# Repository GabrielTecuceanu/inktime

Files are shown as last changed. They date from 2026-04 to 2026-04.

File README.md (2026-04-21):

# InkTime

---

## Block Diagram

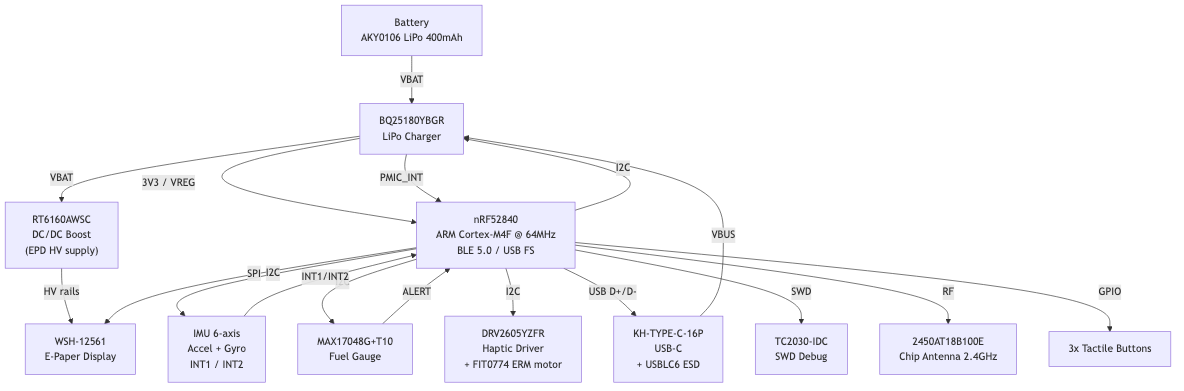
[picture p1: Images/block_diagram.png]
Block Diagram


---

## Bill of Materials (BOM)

| Ref | Component | Description | Package | JLCPCB Part | Datasheet |
| --- | --- | --- | --- | --- | --- |
| U1 | nRF52840-QIAA | MCU, BLE 5.0, ARM Cortex-M4F, 1MB Flash, 256KB RAM | AQFN-73 | [C190794](https://jlcpcb.com/partdetail/NordicSemiconductor-nRF52840_QIAA/C190794) | [Datasheet](https://infocenter.nordicsemi.com/pdf/nRF52840_PS_v1.1.pdf) |
| IC1 | BQ25180YBGR | LiPo charger, I2C, 1A, integrated power path | DSBGA-8 | [C2678722](https://jlcpcb.com/partdetail/TexasInstruments-BQ25180YBGR/C2678722) | [Datasheet](https://www.ti.com/lit/ds/symlink/bq25180.pdf) |
| U3 | MAX17048G+T10 | Fuel gauge, 1% SOC accuracy, I2C | TDFN-8 | [C82344](https://jlcpcb.com/partdetail/MaximIntegrated-MAX17048GT10/C82344) | [Datasheet](https://datasheets.maximintegrated.com/en/ds/MAX17048-MAX17049.pdf) |
| IC9 | RT6160AWSC | DC/DC boost/buck converter for EPD supply, I2C | WL-CSP-15 | Search RT6160AWSC | [Datasheet](https://www.richtek.com/assets/product_file/RT6160A/DS6160A-02.pdf) |
| IC2 | DRV2605YZFR | Haptic driver, I2C, LRA/ERM support | DSBGA-16  | [C2062186](https://jlcpcb.com/partdetail/TexasInstruments-DRV2605YZFR/C2062186) | [Datasheet](https://www.ti.com/lit/ds/symlink/drv2605.pdf) |
| IC3 | BMA423 | 3-axis accelerometer, step counter, I2C | LGA-12 | Search BMA423 | [Datasheet](https://www.bosch-sensortec.com/products/motion-sensors/accelerometers/bma423/)  |
| D3 | USBLC6-2SC6Y | USB ESD protection | SOT-23-6  | [C2827654](https://jlcpcb.com/partdetail/STMicroelectronics-USBLC62SC6Y/C2827654)  | [Datasheet](https://www.st.com/resource/en/datasheet/usblc6-2.pdf) |
| D2, D4, D5 | MBR0530 | Schottky diode, 30V 500mA (EPD drive circuit) | SOD-123 | Search MBR0530 | - |
| Q1 | DMG2305UX-7 | P-channel MOSFET, 20V 4.2A (EPD power switch) | SOT-23-3  | Search DMG2305UX | - |
| Q3 | SI1308EDL-T1-GE3 | N-channel MOSFET, 30V 1.5A (EPD drive circuit) | SC-70 | Search SI1308EDL | - |
| J1 | 503480-2400 | FPC connector 0.5mm 24-pin (e-paper display) | SMD | Search 503480-2400 | - |
| J2 | TC2030-IDC | Tag-Connect SWD debug connector, 6-pin | THT | - | [Datasheet](https://www.tag-connect.com/wp-content/uploads/bsk-pdf-manager/TC2030-IDC_1.pdf) |
| J4 | KH-TYPE-C-16P | USB-C connector, 16-pin | SMD | Search KH-TYPE-C-16P | - |
| ANT1 | 2450AT18B100E | 2.4 GHz chip antenna, 50 Ω | SMD | Search 2450AT18B100E | [Datasheet](https://www.johansontechnology.com/datasheets/antennas/2450AT18B100E.pdf) |
| L5, L7 | FTC252012SR47MBCA  | Power inductor 0.47 µH (EPD boost circuit) | 2016 | [C5832368](https://jlcpcb.com/partdetail/6763488-FTC252012SR47MBCA/C5832368) | - |
| SW_UP, SW_ENT, SW_DN | EVP-AKE31A | Tactile switch (UP / ENTER / DOWN) | SMD | Search EVP-AKE31A | - |
| X1 | 32 MHz crystal | HF clock for nRF52840 radio | 2016 | - | - |
| X2 | 32.768 kHz crystal | LFXO for RTC | 3215 | - | - |
| M1 | DFRobot FIT0774 | ERM haptic motor (shaker) | - | - | [Datasheet](https://www.dfrobot.com/product-1784.html) |
| BAT1 | AKY0106 | LiPo battery 400 mAh, 3.7V | - | - | [Datasheet](https://www.tme.eu/Document/b9e12bf26ad0ba929a22ab5d58f022cd/AKY0106.pdf) |
| DSP1 | WSH-12561 | E-paper display, SPI interface | - | - | [Datasheet](https://www.tme.eu/Document/0ca57a8ffbcd57b5bca53252eb9d6ec3/WSH-12561.pdf) |
| R1–Rn | Various | Resistors 0201, values per schematic | 0201 | - | - |
| C1–Cn | Various | Capacitors 0201 (≤100nF), 0402 (>100nF) | 0201/0402 | - | - |

---

## Hardware Description

### MCU - nRF52840

The nRF52840 is the central processing unit of InkTime. It integrates:

- **ARM Cortex-M4F** at 64 MHz with FPU
- **BLE 5.0** (used for time sync, notifications)
- **USB 2.0 Full Speed** (charging detection and firmware updates)
- **1 MB Flash / 256 KB RAM**

All peripherals are connected directly to the nRF52840 via SPI (e-paper display) and I2C (accelerometer, fuel gauge, haptic driver, PMIC, EPD boost).

### Power Path

```
USB-C --> BQ25180 (charger)    --> LiPo battery (AKY0106, 400 mAh)
                               --> 3.3V rail (VREG, for MCU and all peripherals)
Battery --> RT6160AWSC (boost) --> EPD high-voltage supply (VCOM, gate voltages)
```

- **BQ25180YBGR** manages LiPo charging at up to 1A, monitors VBUS, and raises `PMIC_INT` for fault/status events. Communicates with the MCU over I2C.
- **RT6160AWSC** is a boost converter that generates the higher voltages needed by the e-paper display driver (PREVGH, PREVGL, etc.).
- **MAX17048G+T10** is a ModelGauge fuel gauge that estimates battery state-of-charge (SOC) with 1% accuracy over I2C, using a single-cell LiPo model.

### E-Paper Display - WSH-12561

The e-paper display connects to the MCU over **SPI** plus 3 control GPIOs:

| Signal | Direction  | Description |
| --- | --- | --- |
| SCK | MCU -> EPD | SPI clock |
| MOSI | MCU -> EPD | SPI data |
| EPD_CS | MCU -> EPD | Chip select (active low) |
| EPD_DC | MCU -> EPD | Data / Command select |
| EPD_RST  | MCU -> EPD | Hardware reset (active low) |
| EPD_BUSY | EPD -> MCU | Busy flag (MCU must wait) |

The EPD drive circuit (biased by RT6160AWSC) generates the voltages PREVGH, PREVGL, PREVGL, GDR necessary to drive the e-paper panel.

### IMU - BMA423

3-axis accelerometer connected via **I2C** at 400 kHz. Provides:

- 3-axis accelerometer (step counting, gesture detection, orientation)
- Hardware step counter and activity recognition engine
- Two interrupt lines (`IMU_INT1` -> P0.08, `IMU_INT2` -> P1.08) for wake-on-motion and data-ready events

### Haptic Feedback - DRV2605 + FIT0774

The DRV2605YZFR haptic driver controls the FIT0774 ERM motor. It connects to the MCU over **I2C** and has a digital enable signal `HAPTIC_EN`. It supports library-based waveform playback (124 built-in effects).

### USB - KH-TYPE-C-16P + USBLC6-2SC6Y

USB-C connector with USBLC6-2SC6Y ESD protection on D+ and D− lines. The MCU detects VBUS presence via a GPIO for charging control handoff. USB D+ / D− connect directly to the nRF52840's USB transceiver.

### Antenna - 2450AT18B100E

2.4 GHz chip antenna placed at the PCB edge, away from metal and ground planes. The PCB is **cutout under the antenna** - no copper pours or signal traces are routed under the antenna keepout area. Impedance matching network (L + C pi filter) is present between the nRF52840 RF pin and the antenna.

### SWD Debug - TC2030-IDC

Tag-Connect TC2030-IDC footprint for in-circuit programming and debugging (no connector needed, uses spring-loaded probe). Test pads TP_SWDIO, TP_SWDCLK, TP_RESET, TP_3.3V, TP_GND are exposed on the PCB silkscreen.

---

## nRF52840 Pin Assignment

| Pin | Net | Connected To | Interface  | Notes |
| --- | --- | --- | --- | --- |
| P0.00  | XL1 | 32.768 kHz crystal (X2) | LFXO | Low-frequency clock |
| P0.01  | XL2 | 32.768 kHz crystal (X2) | LFXO | Low-frequency clock |
| P0.02  | SCK | E-paper display (J1 pin 13) | SPI | SPI clock |
| P0.03  | MOSI | E-paper display (J1 pin 14) | SPI | SPI data |
| P0.05  | EPD_CS | E-paper chip select (J1 pin 12) | GPIO | Active low |
| P0.06  | SDA | BQ25180, MAX17048, DRV2605, BMA423, RT6160 | I2C | Shared I2C bus, 3.3 kΩ pull-up to 3V3 |
| P0.07  | SCL | BQ25180, MAX17048, DRV2605, BMA423, RT6160 | I2C | Shared I2C bus, 3.3 kΩ pull-up to 3V3 |
| P0.08  | IMU_INT1  | BMA423 interrupt 1 | GPIO input | Wake-on-motion / step counter |
| P0.09  | RF | Antenna matching network → ANT1 | RF | Dedicated RF pin, PCB cutout required |
| P0.10  | ALERT | MAX17048 alert output | GPIO input | Active low, low battery threshold |
| P0.11  | PMIC_INT  | BQ25180 interrupt | GPIO input | Active low, fault/status events |
| P0.12  | HAPTIC_EN | DRV2605 enable (IC2) | GPIO | Active high |
| P0.13  | SW_UP | Button UP (SW_UP) | GPIO | Active low, external pull-up |
| P0.14  | SW_ENT | Button ENTER (SW_ENT) | GPIO | Active low, external pull-up |
| P0.15  | EPD_DC | E-paper data/command (J1 pin 11) | GPIO | High = data, Low = command |
| P0.16  | EPD_RST | E-paper reset (J1 pin 10) | GPIO | Active low |
| P0.17  | EPD_BUSY  | E-paper busy (J1 pin 9) | GPIO input | Poll or interrupt |
| P0.18  | RESET | Hardware reset, TC2030 pin 6 | RESET | Active low |
| P1.00  | SWO | TP_SWO test point | SWD | Serial Wire Output (trace) |
| P1.02  | SW_DN | Button DOWN (SW_DN) | GPIO | Active low, external pull-up |
| P1.08  | IMU_INT2  | BMA423 interrupt 2 | GPIO input | Data ready |
| SWDIO  | SWDIO | TC2030 pin 2 / TP_SWDIO | SWD | Programming & debug |
| SWDCLK | SWDCLK | TC2030 pin 4 / TP_SWDCLK | SWD | Programming & debug |
| D+ | D+ | USB-C D+ via D3 (ESD) | USB | Full-speed USB |
| D− | D− | USB-C D− via D3 (ESD) | USB | Full-speed USB |
| VBUS | VBUS | USB-C VBUS detect | GPIO input | 5V presence detect |

---

## Power Consumption Estimates

| State | Components active | Estimated current |
| --- | --- | --- |
| Deep sleep | nRF52840 RTC only | ~3 µA |
| BLE advertising | MCU + BLE radio | ~3 mA avg |
| E-paper refresh | MCU + EPD + boost | ~30 mA peak (1-2 s) |
| IMU active | MCU + IMU | ~1.5 mA |
| Full operation (BLE + EPD refresh + IMU) | All | ~35 mA peak |

Battery life estimate (400 mAh, mostly in BLE-advertising + sleep mode)

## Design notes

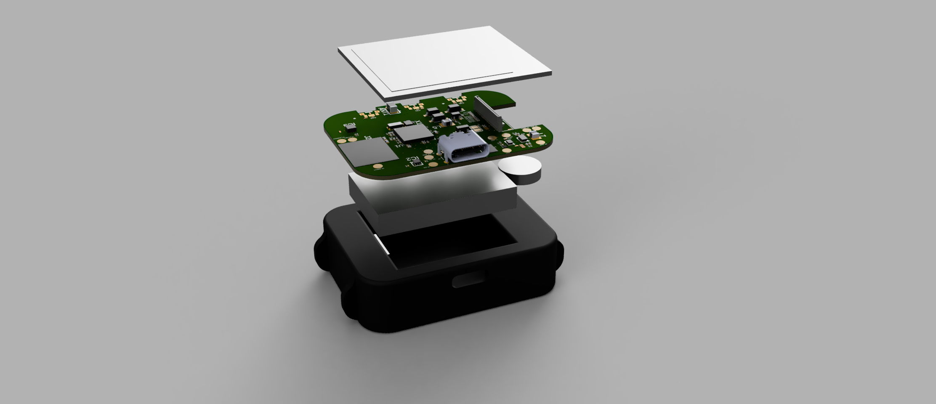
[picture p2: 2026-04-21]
Images/e2.png

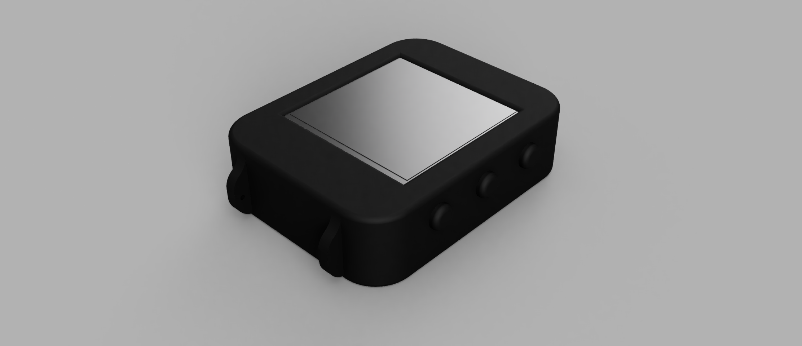
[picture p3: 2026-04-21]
Images/d1.png

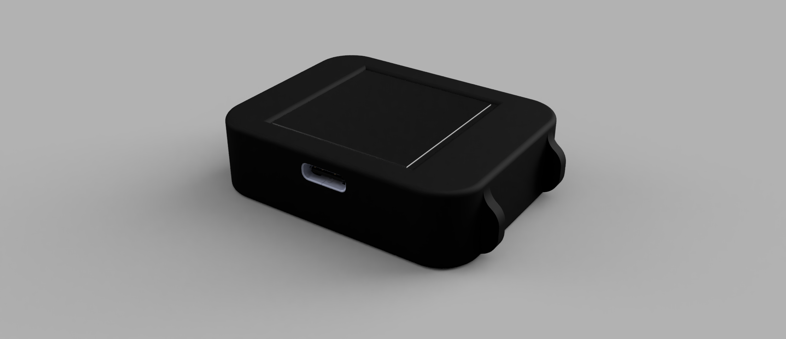
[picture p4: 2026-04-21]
Images/d2.png

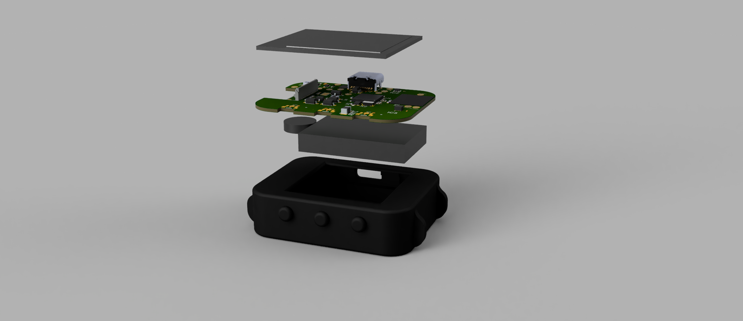
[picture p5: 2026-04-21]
Images/e1.png

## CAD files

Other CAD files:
Mechanical/3dModel.f3d

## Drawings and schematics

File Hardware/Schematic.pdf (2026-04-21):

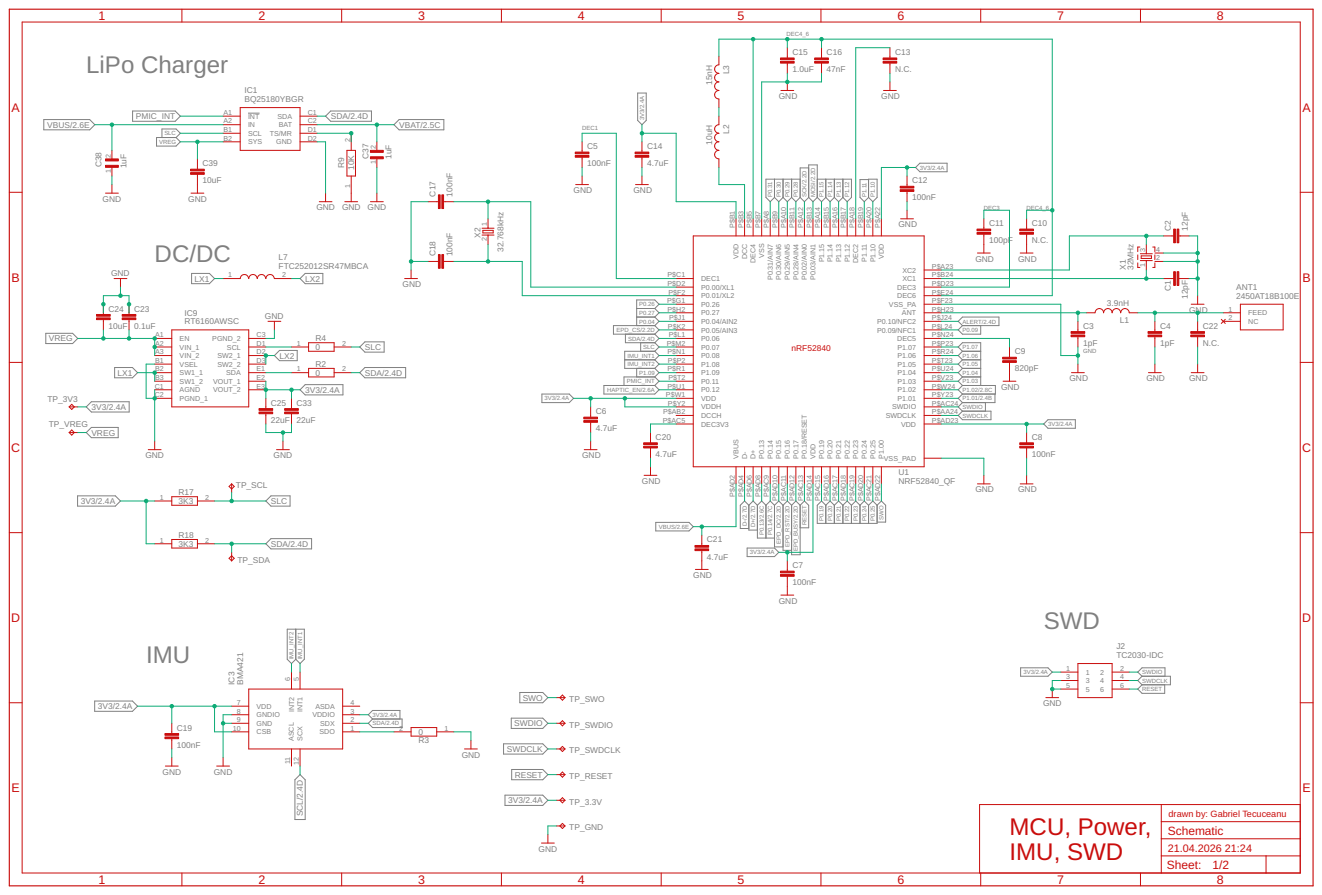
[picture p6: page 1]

drawn by: Gabriel Tecuceanu MCU, Power,
IMU, SWD

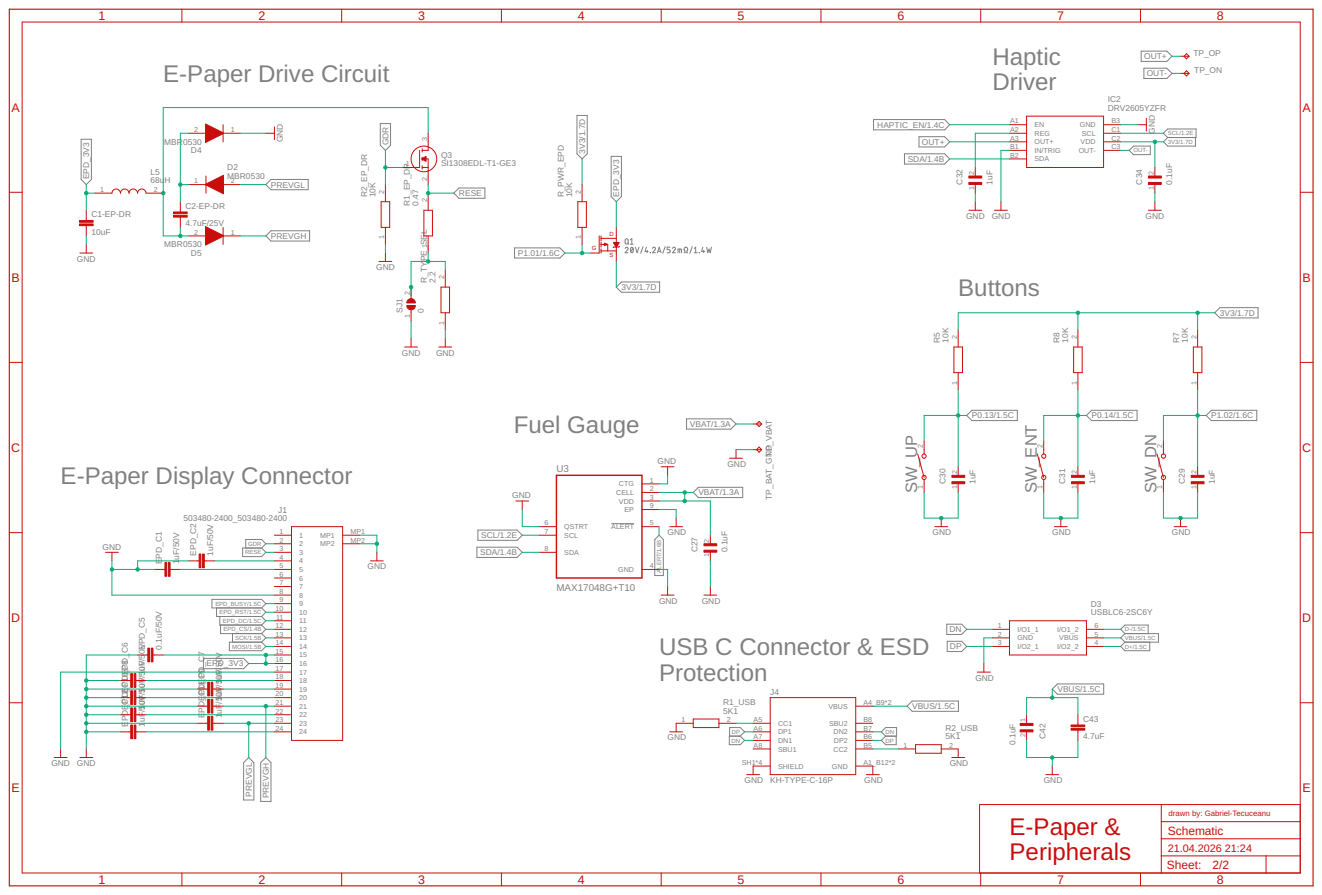
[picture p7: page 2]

Driver | OUT+ HAPTIC_EN/1.4C

23
24

drawn by: Gabriel-Tecuceanu E-Paper &
Peripherals

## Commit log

2026-04-10 feat: add schematic
2026-04-10 feat: add PCB
2026-04-10 feat: add gerber files
2026-04-10 feat: add BOM and PnP
    [BOM.csv, PnP.csv]
2026-04-10 feat: add 3d models
    [3dModel.f3d]
2026-04-10 feat: add render of board
2026-04-21 fix: place and route components on PCB
2026-04-21 fix: add models for display, shaker and battery and update device models
    fixes #5, #6
    [3dModel.f3d]
2026-04-21 update manufacturing files
    [BOM.csv, PnP.csv]
2026-04-21 docs: add pin connections to readme
    fixes #4
